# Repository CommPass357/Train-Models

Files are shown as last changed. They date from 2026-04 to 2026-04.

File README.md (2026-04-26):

# Train-Models

## UP #80 Coal Turbine

- Latest Android app release: [v1.0.6 Android Startup Fix](https://github.com/CommPass357/Train-Models/releases/tag/v1.0.6)
- Latest printable manufacturing release: [v1.0.4](https://github.com/CommPass357/Train-Models/releases/tag/v1.0.4)
- v1.0.4 model files in Git: [models/up-80-coal-turbine/v1.0.4](https://github.com/CommPass357/Train-Models/tree/main/models/up-80-coal-turbine/v1.0.4)
- v1.0.6 Android app source in Git: [models/up-80-coal-turbine/v1.0.6-android-app](https://github.com/CommPass357/Train-Models/tree/main/models/up-80-coal-turbine/v1.0.6-android-app)
- v1.0.5 Android app source in Git: [models/up-80-coal-turbine/v1.0.5-android-app](https://github.com/CommPass357/Train-Models/tree/main/models/up-80-coal-turbine/v1.0.5-android-app)
- v1.0.4 Android app source in Git: [models/up-80-coal-turbine/v1.0.4-android-app](https://github.com/CommPass357/Train-Models/tree/main/models/up-80-coal-turbine/v1.0.4-android-app)
- Android preview release: [v1.0.2 Android Preview](https://github.com/CommPass357/Train-Models/releases/tag/v1.0.2)
- Android preview zip: [up80-android-preview-v1.0.2.zip](https://github.com/CommPass357/Train-Models/releases/download/v1.0.2/up80-android-preview-v1.0.2.zip)
- Preview files in Git: [models/up-80-coal-turbine/v1.0.2-preview](https://github.com/CommPass357/Train-Models/tree/main/models/up-80-coal-turbine/v1.0.2-preview)

The Android app is for phone viewing and quick GitHub downloads. The printable STL/STEP/DXF manufacturing files are in v1.0.4; v1.0.1 remains the earlier baseline manufacturing package.

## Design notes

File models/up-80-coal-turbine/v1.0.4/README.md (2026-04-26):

# HO Union Pacific #80 Coal Turbine v1.0.4

This package is a cleaner printable kit for a three-unit HO scale Union Pacific #80 coal turbine: A/control unit, center turbine unit, and Challenger-style coal tender.

v1.0.4 keeps one shell STL per unit and split chassis parts, then adds a denser reference-informed shell detail pass for phone/app review and first print checks.

Scale target: 1:87.1. The reported 226 ft prototype length scales to 790.9 mm / 31.14 in overall.

## Included
- Parametric Python source and JSON dimensions in `source/`.
- One shell file per unit in `exports/stl/shells/`.
- Split chassis part files in `exports/stl/chassis_parts/`.
- Detail sprues and test coupons in `exports/stl/details/`.
- 3MF print-set previews in `exports/3mf/`.
- Faceted split-chassis STEP references and metal plate DXF in `exports/step/` and `exports/dxf/`.
- Paint masks, decal placement guides, glazing guides, BOM, research notes, and build notes in `docs/`.

## Important Limits
These files are generated from public dimensional references and photo/model-informed proportions. v1.0.4 adds visible grilles, doors, windows, lights, number boards, roof fittings, walkways, handrails, tender ribs, and coal/turbine equipment suggestions, but it is still not a blueprint-grade historical CAD master. Final fit depends on donor trucks, motors, couplers, printer, resin/plastic shrink, and builder wiring.

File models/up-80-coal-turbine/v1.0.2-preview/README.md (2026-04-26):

# UP #80 Android Preview v1.0.2

This is a phone-friendly visual preview of the v1.0.1 HO Union Pacific #80 coal turbine kit.

Open `index.html` in Android Chrome, Edge, or Samsung Internet after extracting the zip. The default view shows the three shell units as a consist. Use the selector for the full kit gallery, including split chassis parts, detail sprue, and test coupons.

## Contents
- `index.html`: mobile WebGL viewer.
- `app.js` and `style.css`: viewer controls and layout.
- `data/preview_meshes.js`: lightweight preview mesh data generated from v1.0.1 STL files.
- `preview_manifest.json`: source files, groups, triangle counts, and release links.

## Counts
- Shell preview files: 3
- Total preview parts: 53
- Source manufacturing version: v1.0.1

For printable files, use the v1.0.1 manufacturing release:
https://github.com/CommPass357/Train-Models/releases/tag/v1.0.1

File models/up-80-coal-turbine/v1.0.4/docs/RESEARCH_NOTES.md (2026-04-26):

# Research Notes

Confirmed/included facts:
- UP #80 was a three-unit coal-burning gas turbine-electric experiment built in 1962.
- The consist used a modified ALCO PA-style control unit, a W-1-derived turbine/electric center unit, and a Challenger-style coal tender.
- Reported overall length is 226 ft, which scales to about 790.9 mm in HO at 1:87.1.
- The prototype was originally #80 and later renumbered #8080; model/decal guides include both.
- Existing OMI/MTH model references support a powered lead unit, powered center unit, and unpowered tender arrangement.

Modeled as inferred/approximate:
- Exact side grille count, small door placement, roof equipment spacing, handrail routing, tender equipment, and underframe equipment are photo/model-informed approximations.
- Chassis mechanics are deliberately functional rather than historically exact.
- Commercial donor drivetrain interfaces are parametric and should be measured against parts on hand before final machining.

Source links used in planning:
- https://locomotive.fandom.com/wiki/Union_Pacific_No._80
- https://www.mthtrains.com/products/20-2678-1
- https://www.mthtrains.com/products/20-21055-1
- https://www.brasstrains.com/classic/Product/Detail/068360/HO-Scale-Brass-Model-Train-OMI-5096-UP-Union-Pacific-8080-Ex-80-Coal-Turbine-Custom
- https://trainiax.net/mephase-alcofa.php
- https://trucolorpaint.com/products/paint/
- https://houseoftrains.com/products/microscale-87-580-ho-union-pacific-8080-coal-turbine-locomotive

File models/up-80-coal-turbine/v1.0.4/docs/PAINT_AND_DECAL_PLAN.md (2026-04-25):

# Paint And Decal Plan

## Colors
- Tru-Color TCP-026 Union Pacific Armour Yellow.
- Tru-Color TCP-025 Union Pacific Harbor Mist Gray.
- Black or grimy black for roof exhaust zones, trucks, and underframe.
- Aluminum/stainless color for grilles and metal detail.
- Gloss clear before decals; satin or flat clear after decals/weathering.

## Decals And Stickers
- Recommended commercial decal: Microscale HO 87-580 Union Pacific #8080 coal turbine locomotive, if available.
- The package includes placement guides for original #80 / 80B and later #8080 / 80B variants.
- UP logo artwork is not bundled; use licensed decals or user-supplied art.

## Finish Sequence
1. Wash and fully cure printed parts.
2. Sand and fill visible print artifacts.
3. Prime plastic/resin/metal; use metal prep for brass/aluminum chassis.
4. Spray Harbor Mist Gray areas and roof/underbody dark areas.
5. Mask and spray Armour Yellow body areas.
6. Apply red stripe/lettering decals over gloss.
7. Seal with satin or flat clear.
8. Add restrained coal dust, turbine exhaust soot, road grime, and truck weathering.

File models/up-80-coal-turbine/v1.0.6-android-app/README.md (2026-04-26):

# UP #80 Android Catalog v1.0.6

This release fixes a launch-crash risk by removing newer Android system-insets API calls while keeping the tiny in-app GitHub update button.

The app previews lightweight mesh data for the full v1.0.4 kit and opens GitHub links for selected parts, selected batches, the v1.0.4 manufacturing release, and the full v1.0.4 zip.

## Catalog Counts
- Total preview items: 53
- Shells: 3
- Chassis parts: 48
- Details/test items: 2

## App Behavior
- Small `!` button opens a native update popup with GitHub release links.
- Startup uses only legacy immersive flags for wider Android compatibility.
- Spinner setup now uses the standard collapsed and dropdown layouts.
- Default view shows the three shell units.
- Full catalog view lays out every preview item.
- Part selector previews one selected item.
- Open part opens the raw GitHub file for that item.
- Open batch opens the GitHub folder for that item's batch.
- Download all opens the v1.0.4 manufacturing zip.
- Android system navigation uses immersive mode; swipe from the edge to temporarily reveal phone Back/Home/Recents.

## Build Status
This machine did not have Android SDK/Gradle installed, so no local APK was produced. The repo includes an Android Studio/Gradle project and a GitHub Actions workflow intended to build a debug APK from tag v1.0.6.

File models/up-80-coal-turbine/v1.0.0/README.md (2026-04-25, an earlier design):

# HO Union Pacific #80 Coal Turbine v1.0.0

This package is a complete digital manufacturing set for a three-unit HO scale Union Pacific #80 coal turbine: A/control unit, center turbine unit, and Challenger-style coal tender. Each unit has its own shell and chassis file set.

Scale target: 1:87.1. The reported 226 ft prototype length scales to 790.9 mm / 31.14 in overall.

## Included
- Parametric Python source and JSON dimensions in `source/`.
- High-detail resin STL files in `exports/stl/resin/`.
- FDM/plastic STL and 3MF files in `exports/stl/fdm/` and `exports/3mf/`.
- Faceted STEP interchange files and metal plate DXF in `exports/step/` and `exports/dxf/`.
- Paint masks, decal placement guides, glazing guides, BOM, research notes, and build notes in `docs/`.

## Important Limits
These files are a detailed digital model package generated from public dimensional references and photo/model-informed proportions. Final fit depends on the donor trucks, motors, couplers, printer, resin/plastic shrink, and the builder's chosen wiring. The chassis are functional HO designs, not a historical reproduction of the prototype underframe mechanics.

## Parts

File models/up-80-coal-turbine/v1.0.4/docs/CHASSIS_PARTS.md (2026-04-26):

# Chassis Parts

Each unit now has one shell file and multiple separate chassis parts.

## A/control unit
- `exports/stl/chassis_parts/a_control/a_control_chassis_base_plate.stl`
- `exports/stl/chassis_parts/a_control/a_control_cosmetic_sideframes.stl`
- `exports/stl/chassis_parts/a_control/a_control_decoder_tray.stl`
- `exports/stl/chassis_parts/a_control/a_control_front_coupler_pocket.stl`
- `exports/stl/chassis_parts/a_control/a_control_left_ballast_box.stl`
- `exports/stl/chassis_parts/a_control/a_control_lighting_tray.stl`
- `exports/stl/chassis_parts/a_control/a_control_motor_cradle.stl`
- `exports/stl/chassis_parts/a_control/a_control_pickup_wiper_mounts.stl`
- `exports/stl/chassis_parts/a_control/a_control_rear_coupler_pocket.stl`
- `exports/stl/chassis_parts/a_control/a_control_right_ballast_box.stl`
- `exports/stl/chassis_parts/a_control/a_control_shell_mount_boss_set.stl`
- `exports/stl/chassis_parts/a_control/a_control_speaker_box.stl`
- `exports/stl/chassis_parts/a_control/a_control_truck_bolster_01.stl`
- `exports/stl/chassis_parts/a_control/a_control_truck_bolster_02.stl`
- `exports/stl/chassis_parts/a_control/a_control_wire_retainers.stl`

## Center turbine unit
- `exports/stl/chassis_parts/center_turbine/center_turbine_chassis_base_plate.stl`
- `exports/stl/chassis_parts/center_turbine/center_turbine_cosmetic_sideframes.stl`
- `exports/stl/chassis_parts/center_turbine/center_turbine_decoder_tray.stl`
- `exports/stl/chassis_parts/center_turbine/center_turbine_front_coupler_pocket.stl`
- `exports/stl/chassis_parts/center_turbine/center_turbine_left_ballast_box.stl`
- `exports/stl/chassis_parts/center_turbine/center_turbine_lighting_tray.stl`
- `exports/stl/chassis_parts/center_turbine/center_turbine_motor_cradle.stl`
- `exports/stl/chassis_parts/center_turbine/center_turbine_pickup_wiper_mounts.stl`
- `exports/stl/chassis_parts/center_turbine/center_turbine_rear_coupler_pocket.stl`
- `exports/stl/chassis_parts/center_turbine/center_turbine_right_ballast_box.stl`
- `exports/stl/chassis_parts/center_turbine/center_turbine_shell_mount_boss_set.stl`
- `exports/stl/chassis_parts/center_turbine/center_turbine_speaker_box.stl`
- `exports/stl/chassis_parts/center_turbine/center_turbine_truck_bolster_01.stl`
- `exports/stl/chassis_parts/center_turbine/center_turbine_truck_bolster_02.stl`
- `exports/stl/chassis_parts/center_turbine/center_turbine_truck_bolster_03.stl`
- `exports/stl/chassis_parts/center_turbine/center_turbine_truck_bolster_04.stl`
- `exports/stl/chassis_parts/center_turbine/center_turbine_wire_retainers.stl`

## Coal tender
- `exports/stl/chassis_parts/coal_tender/coal_tender_chassis_base_plate.stl`
- `exports/stl/chassis_parts/coal_tender/coal_tender_cosmetic_sideframes.stl`
- `exports/stl/chassis_parts/coal_tender/coal_tender_decoder_tray.stl`
- `exports/stl/chassis_parts/coal_tender/coal_tender_front_coupler_pocket.stl`
- `exports/stl/chassis_parts/coal_tender/coal_tender_left_ballast_box.stl`
- `exports/stl/chassis_parts/coal_tender/coal_tender_lighting_tray.stl`
- `exports/stl/chassis_parts/coal_tender/coal_tender_optional_power_truck_adapter.stl`
- `exports/stl/chassis_parts/coal_tender/coal_tender_pickup_wiper_mounts.stl`
- `exports/stl/chassis_parts/coal_tender/coal_tender_rear_coupler_pocket.stl`
- `exports/stl/chassis_parts/coal_tender/coal_tender_right_ballast_box.stl`
- `exports/stl/chassis_parts/coal_tender/coal_tender_shell_mount_boss_set.stl`
- `exports/stl/chassis_parts/coal_tender/coal_tender_speaker_box.stl`
- `exports/stl/chassis_parts/coal_tender/coal_tender_truck_bolster_01.stl`
- `exports/stl/chassis_parts/coal_tender/coal_tender_truck_bolster_02.stl`
- `exports/stl/chassis_parts/coal_tender/coal_tender_truck_bolster_03.stl`
- `exports/stl/chassis_parts/coal_tender/coal_tender_wire_retainers.stl`

## Assembly Notes
- Print base plate flat and test truck swing before gluing or screwing accessories.
- Coupler pockets, bolsters, decoder tray, speaker box, and ballast boxes are separate so they can be reprinted or adjusted independently.
- Use the DXF plate as the metal-cutting reference if replacing printed base plates with brass, aluminum, or stainless.

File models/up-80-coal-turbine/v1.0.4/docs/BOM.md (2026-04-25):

# Bill of Materials

## Recommended Drive And Running Gear
- A/control unit: HO ALCO PA donor mechanism if available, such as Walthers Proto/Proto 2000 or Rapido PA/PB. Use the printed chassis as an adapter pattern and adjust parameters to measured donor geometry.
- Center turbine unit: commercial HO powered trucks or NWSL Stanton-style drives under cosmetic turbine/W-1 sideframes.
- Tender: free-rolling HO tender trucks with optional pickup wipers; the chassis includes optional powered-truck envelope space.

## Couplers And Setup
- Kadee #158 scale whisker couplers with insulated boxes.
- Kadee #205 HO coupler height gauge.
- 2-56 screws for coupler boxes; M1.4/M1.6 or 0-80 screws for shell retention depending on print material.

## DCC, Lighting, And Sound
- ESU LokSound 5 or SoundTraxx TSU-2200 class decoder.
- One diesel speaker in the A unit and one turbine speaker in the center unit.
- Optional keep-alive/power pack in the tender or center unit.
- Warm white LEDs for headlight/Mars/number boards; red/green marker LEDs; resistors sized for the chosen decoder outputs.
- Micro JST connectors between units, fine decoder wire, phosphor-bronze pickup wire.

## Materials
- High-detail resin for shells, vents, grilles, cab details, fans, and tender body.
- PETG/ABS/ASA or tough resin for chassis prototypes; brass, aluminum, or stainless sheet for final chassis plates.
- Clear PETG/acetate for glazing.
- Tungsten putty, lead-free shot, or machined ballast blocks for weight.
- Phosphor-bronze or brass wire for handrails where resin would be fragile.

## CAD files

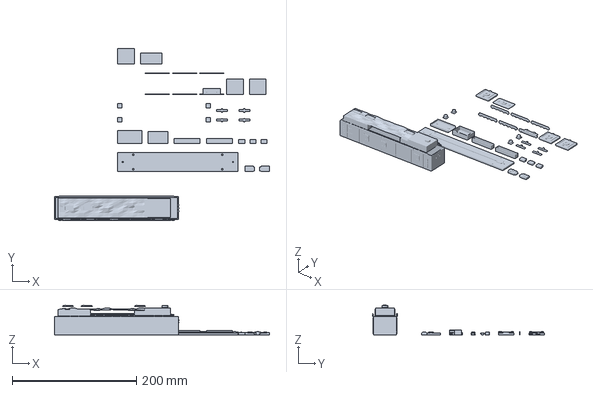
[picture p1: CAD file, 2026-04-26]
models/up-80-coal-turbine/v1.0.4/exports/3mf/coal_tender_shell_and_split_chassis_print_set.3mf
346.8 x 276.8 x 48.1 mm

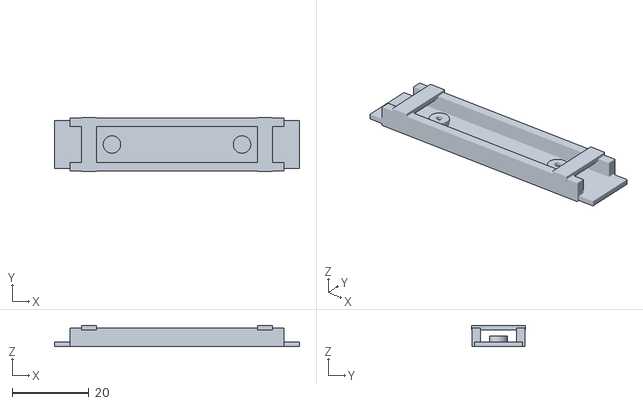
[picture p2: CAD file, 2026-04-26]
models/up-80-coal-turbine/v1.0.4/exports/stl/chassis_parts/a_control/a_control_motor_cradle.stl
64.0 x 14.0 x 5.50

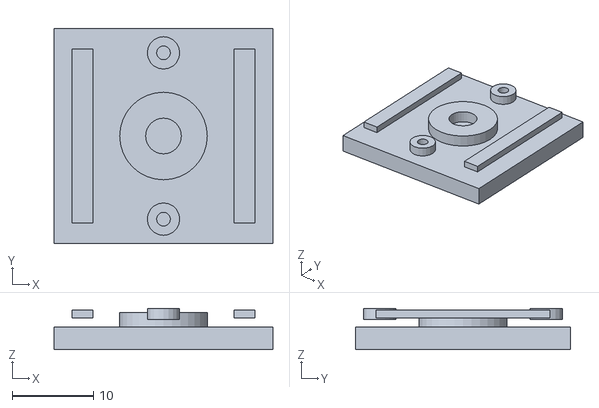
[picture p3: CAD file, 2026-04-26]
models/up-80-coal-turbine/v1.0.4/exports/stl/chassis_parts/center_turbine/center_turbine_truck_bolster_02.stl
27.0 x 26.5 x 5.10

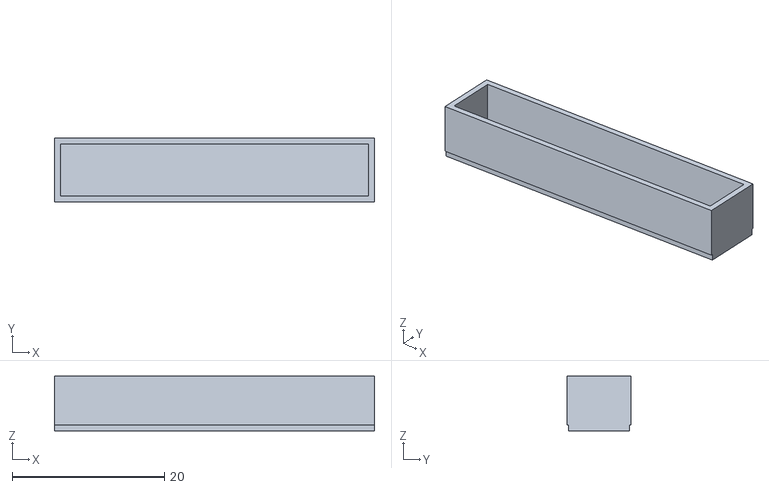
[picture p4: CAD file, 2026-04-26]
models/up-80-coal-turbine/v1.0.4/exports/stl/chassis_parts/coal_tender/coal_tender_right_ballast_box.stl
42.0 x 8.40 x 7.20

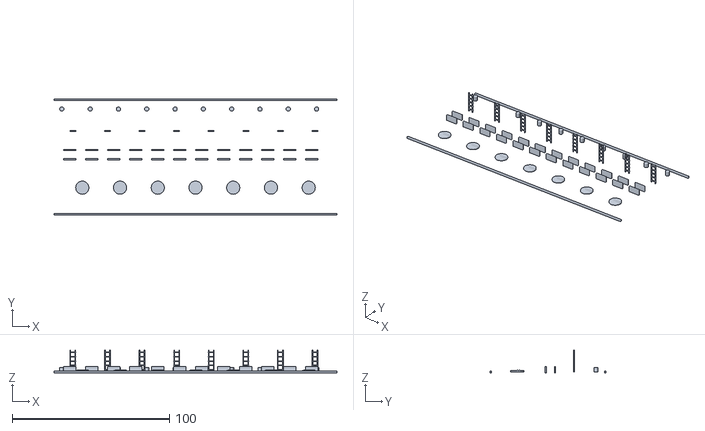
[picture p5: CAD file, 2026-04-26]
models/up-80-coal-turbine/v1.0.4/exports/stl/details/up80_detail_sprue.stl
180.0 x 74.0 x 14.5

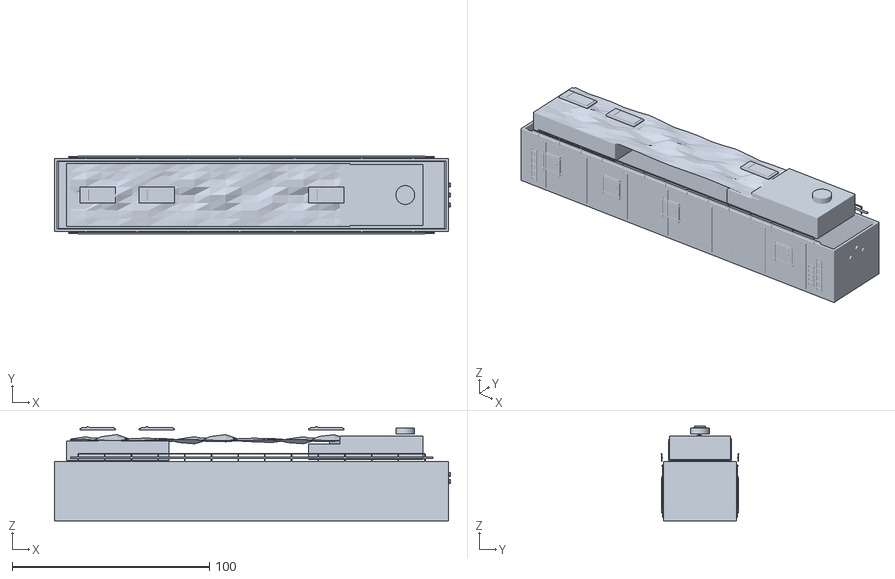
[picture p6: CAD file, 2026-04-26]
models/up-80-coal-turbine/v1.0.4/exports/stl/shells/coal_tender_shell.stl
200.9 x 39.5 x 48.0

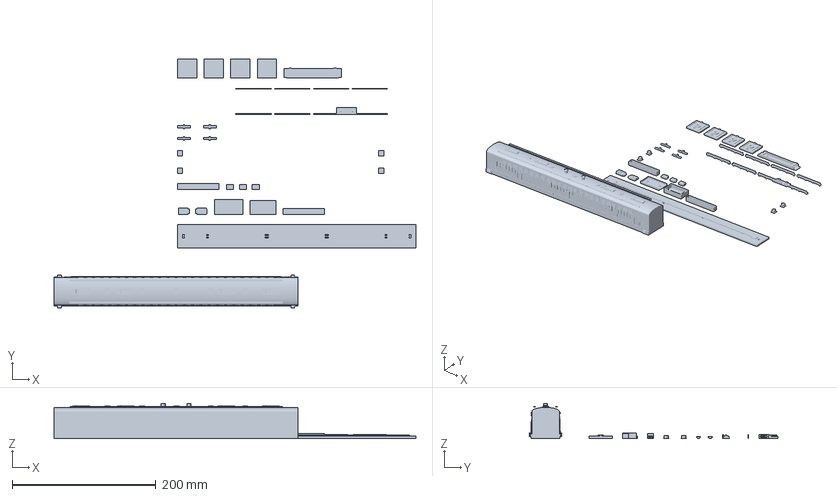
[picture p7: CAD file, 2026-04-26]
models/up-80-coal-turbine/v1.0.4/exports/3mf/center_turbine_shell_and_split_chassis_print_set.3mf
504.0 x 346.1 x 48.9 mm

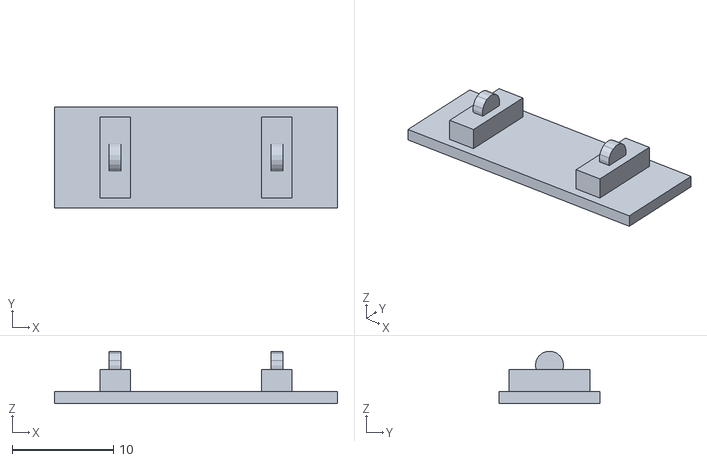
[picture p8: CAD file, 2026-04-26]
models/up-80-coal-turbine/v1.0.4/exports/stl/chassis_parts/a_control/a_control_lighting_tray.stl
28.0 x 10.0 x 5.18

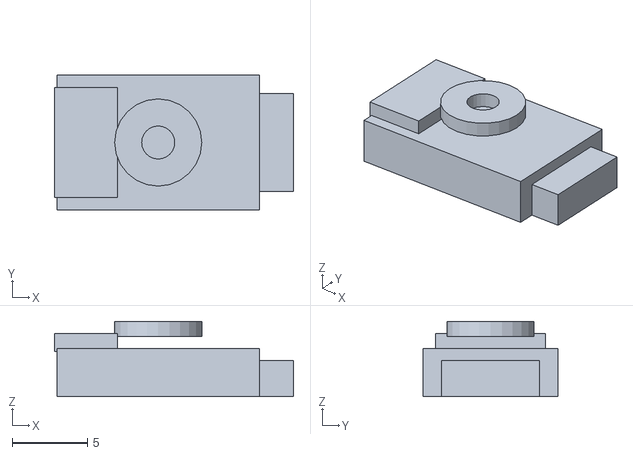
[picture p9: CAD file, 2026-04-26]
models/up-80-coal-turbine/v1.0.4/exports/stl/chassis_parts/coal_tender/coal_tender_front_coupler_pocket.stl
15.9 x 9.00 x 5.00

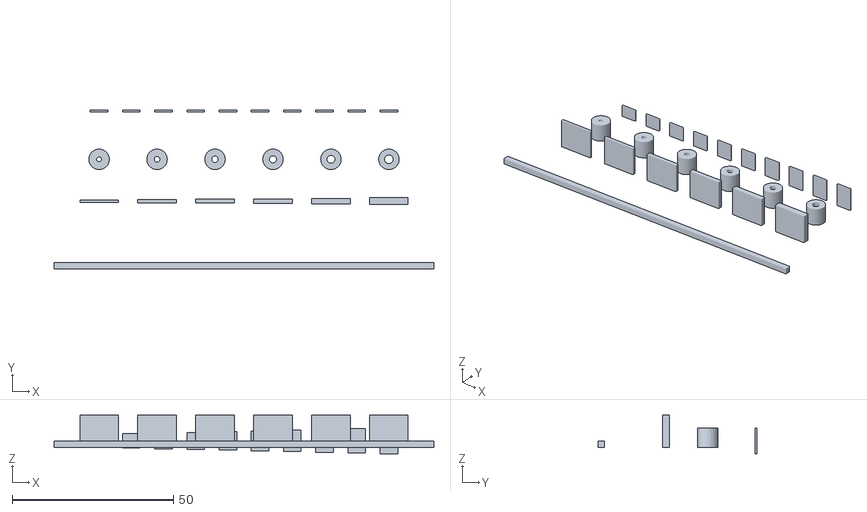
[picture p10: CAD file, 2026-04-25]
models/up-80-coal-turbine/v1.0.4/exports/stl/details/up80_test_coupons.stl
118.0 x 49.2 x 12.0

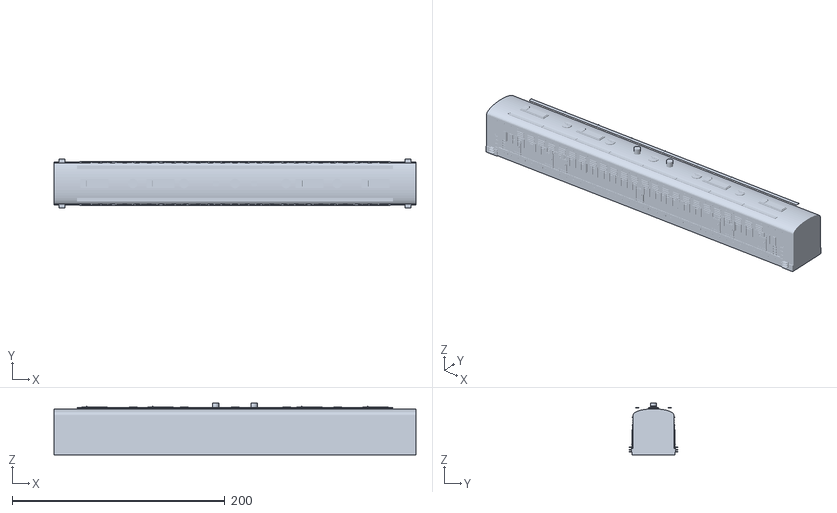
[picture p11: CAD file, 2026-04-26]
models/up-80-coal-turbine/v1.0.4/exports/stl/shells/center_turbine_shell.stl
340.0 x 45.6 x 48.8

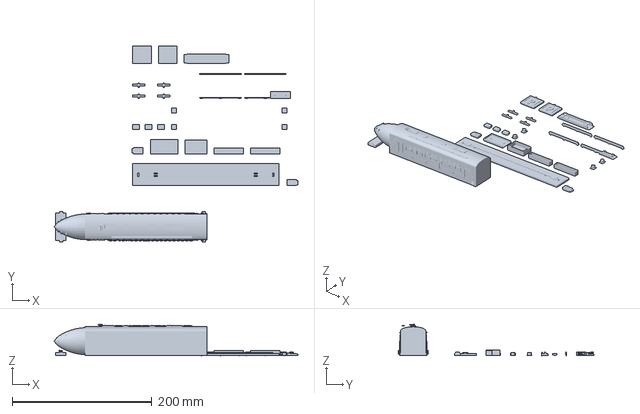
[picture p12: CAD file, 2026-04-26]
models/up-80-coal-turbine/v1.0.4/exports/3mf/a_control_shell_and_split_chassis_print_set.3mf
349.4 x 281.1 x 45.1 mm

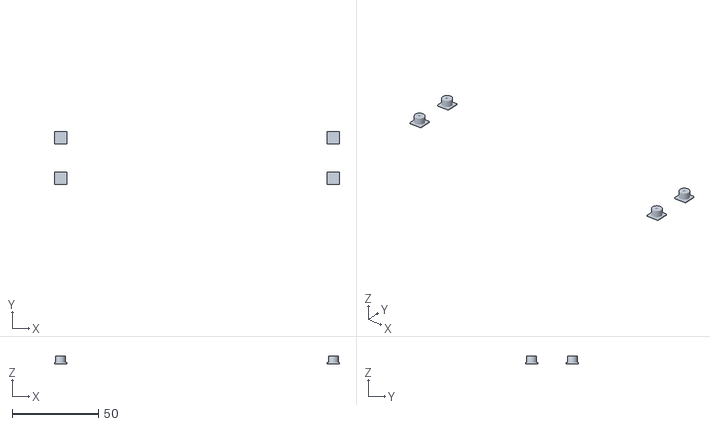
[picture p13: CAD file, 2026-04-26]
models/up-80-coal-turbine/v1.0.4/exports/stl/chassis_parts/a_control/a_control_shell_mount_boss_set.stl
165.2 x 30.7 x 4.40

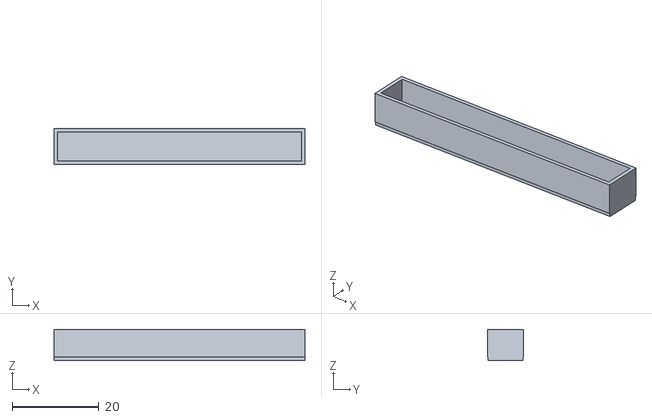
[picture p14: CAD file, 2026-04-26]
models/up-80-coal-turbine/v1.0.4/exports/stl/chassis_parts/center_turbine/center_turbine_right_ballast_box.stl
58.0 x 8.40 x 7.20

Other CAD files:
models/up-80-coal-turbine/v1.0.4/exports/dxf/up80_chassis_plates.dxf
models/up-80-coal-turbine/v1.0.4/exports/stl/chassis_parts/center_turbine/center_turbine_truck_bolster_01.stl
models/up-80-coal-turbine/v1.0.4/exports/stl/chassis_parts/coal_tender/coal_tender_lighting_tray.stl
models/up-80-coal-turbine/v1.0.4/exports/stl/shells/a_control_shell.stl
models/up-80-coal-turbine/v1.0.0/exports/3mf/a_control_fdm_print_set.3mf
models/up-80-coal-turbine/v1.0.0/exports/3mf/center_turbine_fdm_print_set.3mf
models/up-80-coal-turbine/v1.0.0/exports/3mf/coal_tender_fdm_print_set.3mf
models/up-80-coal-turbine/v1.0.0/exports/step/a_control_chassis_faceted.step
models/up-80-coal-turbine/v1.0.0/exports/stl/fdm/a_control_chassis_fdm.stl
models/up-80-coal-turbine/v1.0.0/exports/stl/fdm/a_control_shell_fdm.stl
models/up-80-coal-turbine/v1.0.0/exports/stl/fdm/center_turbine_chassis_fdm.stl
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

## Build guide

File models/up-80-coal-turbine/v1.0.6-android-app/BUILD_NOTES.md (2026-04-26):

# Build Notes

## Android Studio
1. Open `app-project`.
2. Let Android Studio install missing SDK/build tools if prompted.
3. Build `app`.
4. Install the generated APK on Android.

## Command Line
From `app-project`, run:

```powershell
gradle :app:assembleDebug
```

The app uses plain Java Android APIs and local asset JSON. It has no third-party runtime dependencies.

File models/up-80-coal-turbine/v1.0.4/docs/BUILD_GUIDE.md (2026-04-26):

# Build Guide

## Printing
- Use `exports/stl/shells/` for the three one-piece shells.
- Use `exports/stl/chassis_parts/` for the split chassis parts.
- Use `exports/stl/details/` for detail sprues and test coupons.
- Use `exports/3mf/` for quick print-set previews.
- Print small details from `up80_detail_sprue.stl` separately for cleaner painting and easier replacement.
- Print `up80_test_coupons.stl` before committing to full shells.

## Chassis
- The A/control and center turbine chassis are powered-ready split assemblies.
- The tender chassis is a rolling/unpowered split assembly by default, with lighting, pickup, speaker, keep-alive, and optional power-adapter provisions.
- Drill pilot holes to final screw size after printing or machining.
- If using metal plates, cut from `exports/dxf/up80_chassis_plates.dxf`, then transfer printed mounts/trays as needed.

## Assembly
- Fit donor trucks and motor components before painting shells.
- Confirm Kadee coupler height before final wiring.
- Use removable connectors between units so shells can be removed without desoldering.
- Add weight gradually and verify each powered unit independently before coupling the full train.

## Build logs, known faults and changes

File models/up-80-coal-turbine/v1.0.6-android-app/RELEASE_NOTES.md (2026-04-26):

# v1.0.6 Android Startup Fix

Native Android catalog app source for the UP #80 model kit, rebuilt to avoid startup crashes on phones that dislike newer system-insets APIs.

## Added
- Kept the small `!` update button in the top title row.
- Kept the native update popup with links to the latest GitHub release and the current app release.
- Replaced Android 11+ system-insets calls with legacy immersive flags for broader phone compatibility.
- Standardized spinner layout setup.
- Bottom padding for the app command rows to reduce overlap on gesture and three-button Android navigation.
- Local lightweight preview catalog generated from v1.0.4 STL files.
- Three-shell default preview.
- Full catalog preview.
- GitHub links for each part, each batch, chassis docs, and the full v1.0.4 manufacturing zip.

## Notes
- This is an Android app source release; no full STL files are bundled in the APK assets.
- Printable files for this app revision are in v1.0.4.
- APK building requires Android SDK/Gradle or the included GitHub Actions workflow.

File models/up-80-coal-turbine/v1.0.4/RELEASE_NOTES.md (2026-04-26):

# v1.0.4

Android-control fix plus improved visible shell detail for the HO Union Pacific #80 coal turbine.

## Added
- Native Android catalog app source package for v1.0.4, generated from the v1.0.4 STL catalog.
- Android immersive mode so phone navigation buttons hide during preview and return by edge swipe.
- Extra bottom padding in the app command area for phones using gesture or three-button navigation.
- More detailed A/control shell: PA-style windows, number boards, dual headlights, Mars/marker lights, doors, handrails, grilles, rivets, roof hatches, horns, fans, and pilot steps.
- More detailed center turbine shell: dense side grille texture, see-through equipment suggestions, roof fans/stacks/hatches, walkways, handrails, doors, ladders, and pilot steps.
- More detailed tender shell: coal load, tender ribs/rivets, service doors, ladders, handrails, rear lights, pulverizer/crusher equipment, hatches, and deck fittings.
- Continued one-shell-per-unit and split chassis part organization.

## Assets
- `up-80-coal-turbine-ho-v1.0.4.zip`: printable/model package with STL, 3MF, STEP, DXF, docs, source, paint/decal plan, BOM, and validation report.
- `up80-android-app-v1.0.4-source.zip`: native Android app source package.
- `up80-catalog-v1.0.4-debug.apk`: Android debug APK, built by GitHub Actions after the tag is pushed.

## Known Limits
- STEP files are faceted interchange exports generated without a local CAD kernel.
- Donor drive mounting should be adjusted from measured parts before final metal cutting.
- Exterior accuracy is still limited by public/reference-model data until v1.1 CAD and printer feedback are available.

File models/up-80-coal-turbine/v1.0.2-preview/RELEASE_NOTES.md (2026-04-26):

# v1.0.2 Android Preview

Phone web preview release built from the v1.0.1 printable kit.

## Added
- Android-friendly WebGL viewer.
- Default three-shell consist preview.
- Full kit gallery for shells, split chassis parts, detail sprue, and test coupons.
- Lightweight preview mesh data and manifest.

## Notes
- This release is for visual inspection only.
- Printable STL, STEP, DXF, 3MF, BOM, and build files remain in v1.0.1.

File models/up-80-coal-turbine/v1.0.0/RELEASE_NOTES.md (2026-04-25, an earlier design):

# v1.0.0

Initial complete digital manufacturing package for the HO Union Pacific #80 coal turbine.

## Added
- Three unit shells: A/control, center turbine, and coal tender.
- Three independent chassis: powered-ready A/control, powered-ready center turbine, rolling tender.
- Resin STL, FDM STL, 3MF, faceted STEP, DXF, and SVG manufacturing outputs.
- BOM, build guide, paint/decal plan, research notes, manifest, and validation report.

## Known Limits
- STEP files are faceted interchange exports generated without a local CAD kernel.
- Donor drive mounting should be adjusted from measured parts before final metal cutting.

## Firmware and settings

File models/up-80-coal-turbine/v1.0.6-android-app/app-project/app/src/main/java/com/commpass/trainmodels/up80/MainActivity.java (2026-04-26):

package com.commpass.trainmodels.up80;

import android.app.Activity;
import android.app.AlertDialog;
import android.content.Intent;
import android.graphics.Color;
import android.net.Uri;
import android.os.Bundle;
import android.view.View;
import android.view.Window;
import android.widget.AdapterView;
import android.widget.ArrayAdapter;
import android.widget.Button;
import android.widget.LinearLayout;
import android.widget.Spinner;
import android.widget.TextView;
import android.widget.Toast;
import java.util.ArrayList;
import java.util.List;

public final class MainActivity extends Activity {
    private static final String APP_RELEASE_URL = "https://github.com/CommPass357/Train-Models/releases/tag/v1.0.6";
    private static final String LATEST_RELEASE_URL = "https://github.com/CommPass357/Train-Models/releases/latest";
    private CatalogData catalog;
    private MeshPreviewView preview;
    private Spinner spinner;
    private TextView title;
    private TextView info;
    private CatalogItem selected;

    @Override protected void onCreate(Bundle state) {
        super.onCreate(state);
        enableImmersiveMode();
        try {
            catalog = CatalogLoader.load(this);
        } catch (Exception e) {
            TextView error = new TextView(this);
            error.setText("Could not load catalog: " + e.getMessage());
            setContentView(error);
            return;
        }

        LinearLayout root = new LinearLayout(this);
        root.setOrientation(LinearLayout.VERTICAL);
        root.setPadding(dp(12), dp(12), dp(12), dp(34));

        LinearLayout titleRow = new LinearLayout(this);
        titleRow.setOrientation(LinearLayout.HORIZONTAL);
        titleRow.setPadding(0, 0, 0, dp(8));

        title = new TextView(this);
        title.setText("UP #80 Catalog v1.0.6");
        title.setTextSize(20);
        title.setPadding(0, 0, dp(8), 0);
        title.setLayoutParams(new LinearLayout.LayoutParams(0, LinearLayout.LayoutParams.WRAP_CONTENT, 1f));
        titleRow.addView(title);

        Button update = iconButton("!", v -> showUpdateDialog());
        titleRow.addView(update);
        root.addView(titleRow);

        preview = new MeshPreviewView(this);
        root.addView(preview, new LinearLayout.LayoutParams(
            LinearLayout.LayoutParams.MATCH_PARENT, 0, 1f));

        spinner = new Spinner(this);
        ArrayAdapter<CatalogItem> adapter = new ArrayAdapter<>(this, android.R.layout.simple_spinner_item, catalog.parts);
        adapter.setDropDownViewResource(android.R.layout.simple_spinner_dropdown_item);
        spinner.setAdapter(adapter);
        root.addView(spinner);

        info = new TextView(this);
        info.setPadding(0, 8, 0, 8);
        root.addView(info);

        LinearLayout row1 = row();
        row1.addView(button("3 shells", v -> showShells()));
        row1.addView(button("Full catalog", v -> showFullCatalog()));
        row1.addView(button("Reset", v -> preview.resetCamera()));
        root.addView(row1);

        LinearLayout row2 = row();
        row2.addView(button("Preview part", v -> showSelected()));
        row2.addView(button("Open part", v -> open(selected.partUrl)));
        row2.addView(button("Open batch", v -> open(selected.batchUrl)));
        root.addView(row2);

        LinearLayout row3 = row();
        row3.addView(button("Download all", v -> open(catalog.manufacturingZipUrl)));
        row3.addView(button("v1.0.4 files", v -> open(catalog.manufacturingReleaseUrl)));
        row3.addView(button("Chassis docs", v -> open(catalog.chassisPartsDocUrl)));
        root.addView(row3);

        setContentView(root);
        root.post(this::enableImmersiveMode);
        selected = catalog.parts.get(0);
        spinner.setOnItemSelectedListener(new AdapterView.OnItemSelectedListener() {
            @Override public void onItemSelected(AdapterView<?> parent, View view, int position, long id) {
                selected = catalog.parts.get(position);
                updateInfo(selected);
            }
            @Override public void onNothingSelected(AdapterView<?> parent) {}
        });
        showShells();
    }

    @Override public void onWindowFocusChanged(boolean hasFocus) {
        super.onWindowFocusChanged(hasFocus);
        if (hasFocus) enableImmersiveMode();
    }

    private void enableImmersiveMode() {
        Window window = getWindow();
        window.setStatusBarColor(Color.TRANSPARENT);
        window.setNavigationBarColor(Color.TRANSPARENT);
        window.getDecorView().setSystemUiVisibility(
            View.SYSTEM_UI_FLAG_IMMERSIVE_STICKY
            | View.SYSTEM_UI_FLAG_FULLSCREEN
            | View.SYSTEM_UI_FLAG_HIDE_NAVIGATION
            | View.SYSTEM_UI_FLAG_LAYOUT_HIDE_NAVIGATION
            | View.SYSTEM_UI_FLAG_LAYOUT_FULLSCREEN
            | View.SYSTEM_UI_FLAG_LAYOUT_STABLE
        );
    }

    private int dp(int value) {
        return Math.round(value * getResources().getDisplayMetrics().density);
    }

    private LinearLayout row() {
        LinearLayout row = new LinearLayout(this);
        row.setOrientation(LinearLayout.HORIZONTAL);
        return row;
    }

    private Button button(String text, View.OnClickListener listener) {
        Button button = new Button(this);
        button.setText(text);
        button.setAllCaps(false);
        button.setOnClickListener(listener);
        button.setLayoutParams(new LinearLayout.LayoutParams(0, LinearLayout.LayoutParams.WRAP_CONTENT, 1f));
        return button;
    }

    private Button iconButton(String text, View.OnClickListener listener) {
        Button button = new Button(this);
        button.setText(text);
        button.setTextSize(14);
        button.setAllCaps(false);
        button.setMinWidth(0);
        button.setMinimumWidth(0);
        button.setPadding(0, 0, 0, 0);
        button.setOnClickListener(listener);
        button.setLayoutParams(new LinearLayout.LayoutParams(dp(34), dp(34)));
        return button;
    }

    private void showUpdateDialog() {
        new AlertDialog.Builder(this)
            .setTitle("GitHub update")
            .setMessage("App v1.0.6 previews the v1.0.4 model package. Open GitHub to get the newest APK, source, or printable model files.")
            .setPositiveButton("Latest", (dialog, which) -> open(LATEST_RELEASE_URL))
            .setNeutralButton("This app", (dialog, which) -> open(APP_RELEASE_URL))
            .setNegativeButton("Close", null)
            .show();
    }

    private void showShells() {
        List<PreviewItem> items = new ArrayList<>();
        for (String id : new String[] {"a_control_shell", "center_turbine_shell", "coal_tender_shell"}) {
            CatalogItem item = catalog.byId.get(id);
            if (item == null) continue;
            float[] offset = catalog.shellOffsets.containsKey(id) ? catalog.shellOffsets.get(id) : new float[] {0f, 0f, 0f};
            items.add(new PreviewItem(item, offset));
        }
        if (items.isEmpty()) {
            info.setText("No shell preview items were found in the catalog.");
            return;
        }
        title.setText("UP #80 - three shell preview");
        info.setText("Default view: A/control shell, center turbine shell, and tender shell. Drag to rotate; pinch to zoom.");
        preview.setPreviewItems(items);
    }

    private void showFullCatalog() {
        List<PreviewItem> items = new ArrayList<>();
        float x = 0f, y = 0f, rowHeight = 0f;
        for (CatalogItem item : catalog.parts) {
            float width = item.mesh.boundsMax[0] - item.mesh.boundsMin[0];
            float height = item.mesh.boundsMax[1] - item.mesh.boundsMin[1];
            if (x + width > 520f) {
                x = 0f;
                y += rowHeight + 18f;
                rowHeight = 0f;
            }
            items.add(new PreviewItem(item, new float[] {x + width * 0.5f, y + height * 0.5f, 0f}));
            x += width + 14f;
            rowHeight = Math.max(rowHeight, height);
        }
        title.setText("Full catalog preview");
        info.setText(catalog.parts.size() + " preview items. Use Open part, Open batch, or Download all for the real files on GitHub.");
        preview.setPreviewItems(items);
    }

    private void showSelected() {
        if (selected == null) return;
        title.setText(selected.label);
        updateInfo(selected);
        List<PreviewItem> items = new ArrayList<>();
        items.add(new PreviewItem(selected, new float[] {0f, 0f, 0f}));
        preview.setPreviewItems(items);
    }

    private void updateInfo(CatalogItem item) {
        if (item == null) return;
        info.setText(item.group + " | " + item.sourceTriangles + " STL triangles -> " + item.previewTriangles + " preview triangles");
    }

    private void open(String url) {
        if (url == null || url.length() == 0) {
            Toast.makeText(this, "No link for this item", Toast.LENGTH_SHORT).show();
            return;
        }
        startActivity(new Intent(Intent.ACTION_VIEW, Uri.parse(url)));
    }
}

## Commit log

2026-04-25 Add UP #80 coal turbine HO model v1.0.0
    [a_control_chassis_faceted.step, a_control_chassis_fdm.stl, a_control_chassis_resin.stl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]
2026-04-26 Add UP #80 coal turbine HO model v1.0.1
    [a_control_chassis_base_plate.stl, a_control_cosmetic_sideframes.stl, a_control_decoder_tray.stl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]
2026-04-26 Add UP80 v1.0.4 shell detail and Android fix
    [a_control_chassis_base_plate.stl, a_control_cosmetic_sideframes.stl, a_control_decoder_tray.stl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]
2026-04-26 Fix UP80 Android startup compatibility
    [MainActivity.java]
